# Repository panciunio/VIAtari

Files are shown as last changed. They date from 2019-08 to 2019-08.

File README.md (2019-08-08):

# VIAtari

**Welcome to the VIAtari wiki!**

**Introduction**
Inspiration for this mode I found on Daryl's Computer Hobby Page. Daryl made Composite Video Text/Graphics Display based on ATMEGA8 and drive by VIA6522. This article will show how to build, assembly and connect VIA 6522 IC to Atari and use 2 additional 8-bit parallel ports and serial interface. This is my own project build from scratch but it's nothing modern - this IC was used in C64 to communicate with disk drive. It will be used as additional PIA for manage other equipment.

Notice:
This implementation is designed for Atari 65/130XE with CART/ECI ports available. It's called VIAtariXE

**Why?**
Well, on the market you may find a few sellers which have VIA6522, but...
- this IC is discontinued, don't wait so much time, buy it!
- it's still very useful and may be good alternative for PIA 6520(6521).
- topology and registers covering PIA 6520, so you may use it as equivalent for it. (some pins should be swapped)
- very cheap IC (~2$/piece).

**Best sources**
Original source:
https://systemembedded.eu/viewtopic.php?f=28&t=41

**Discussion (Polish)**

http://www.atari.org.pl/forum/viewtopic.php?id=16098

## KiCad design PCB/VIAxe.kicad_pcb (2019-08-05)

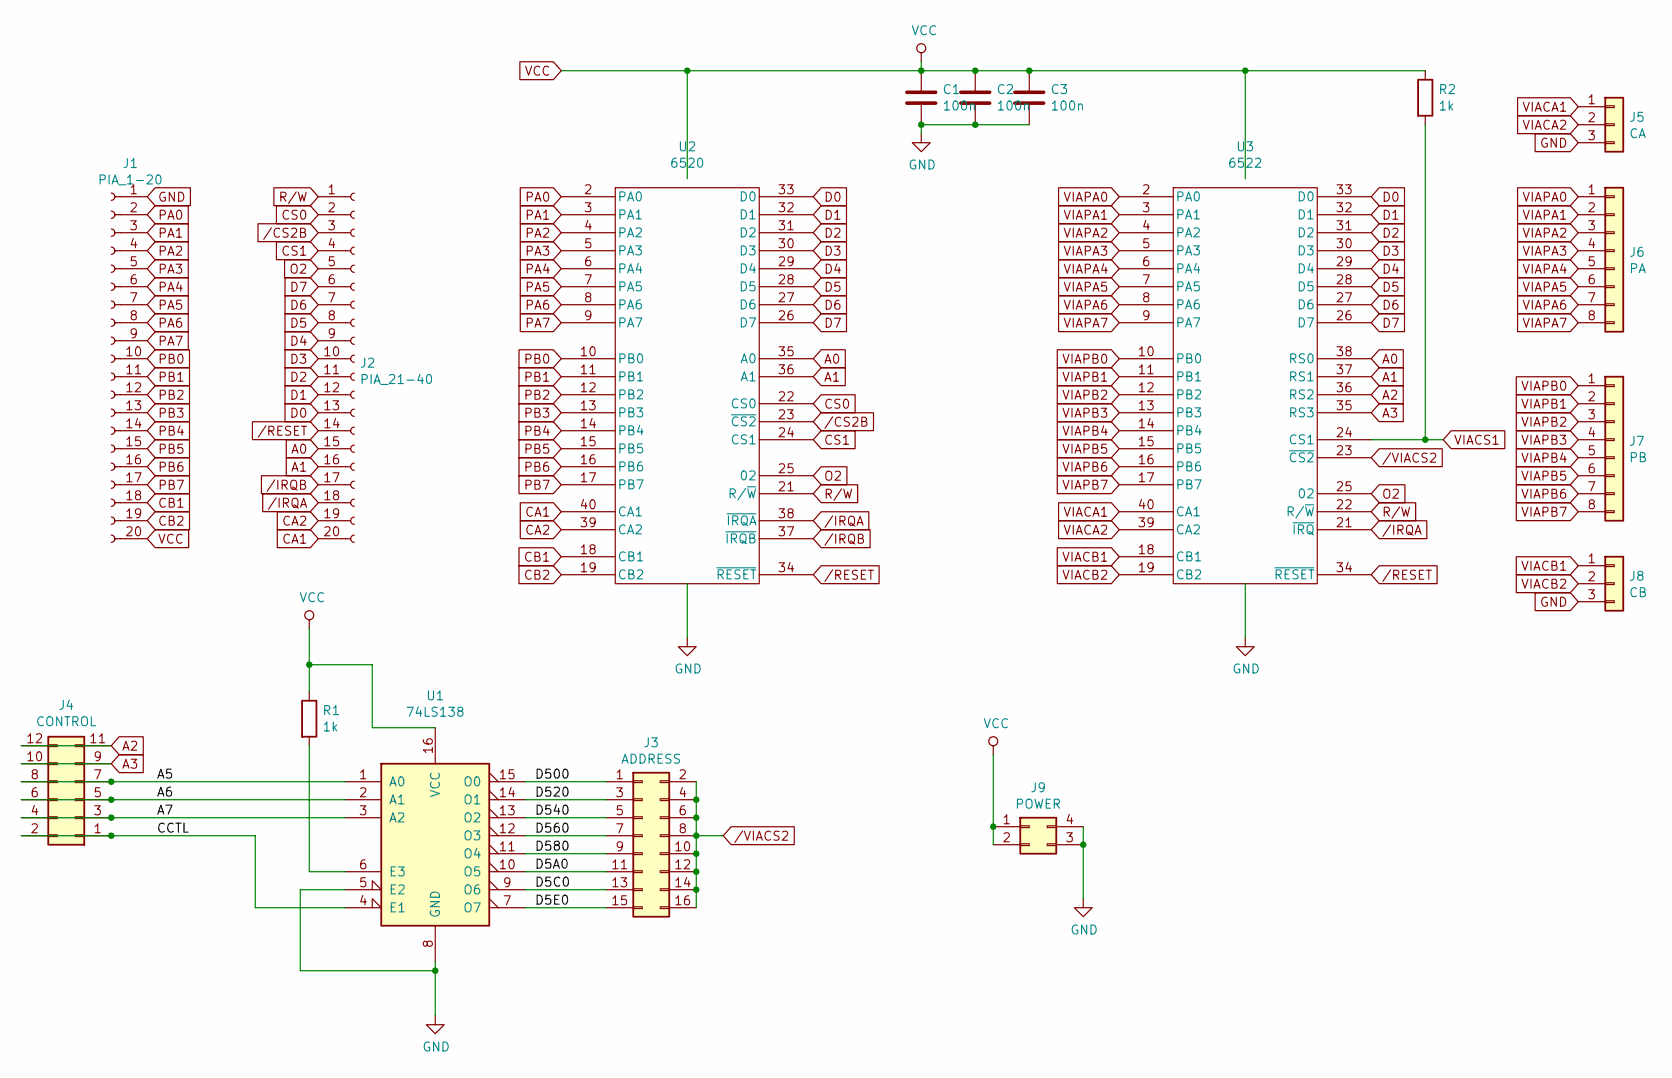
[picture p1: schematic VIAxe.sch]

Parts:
C1, C2, C3: 100n; C_1206_3216Metric
J1: PIA_1-20; PinSocket_1x20_P2.54mm_Vertical
J2: PIA_21-40; PinSocket_1x20_P2.54mm_Vertical
J3: ADDRESS; PinHeader_2x08_P2.54mm_Vertical
J4: CONTROL; PinHeader_2x06_P2.54mm_Vertical
J5: CA; PinHeader_1x03_P2.54mm_Vertical
J6: PA; PinHeader_1x08_P2.54mm_Vertical
J7: PB; PinHeader_1x08_P2.54mm_Vertical
J8: CB; PinHeader_1x03_P2.54mm_Vertical
J9: POWER; PinHeader_2x02_P2.54mm_Vertical
R1, R2: 1k; R_1206_3216Metric
U1: 74LS138; SOP-16_4.4x10.4mm_P1.27mm
U2: 6520; DIP-40_W15.24mm_LongPads
U3: 6522; DIP-40_W15.24mm_LongPads

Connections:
/A5: J4.7, J4.8, U1.1 (A0)
/A6: J4.5, J4.6, U1.2 (A1)
/A7: J4.3, J4.4, U1.3 (A2)
/CCTL: J4.1, J4.2, U1.4 (E1)
/CS2B: J2.3, U2.23 (~CS2)
/D5A0: J3.11, U1.10 (O5)
/D5C0: J3.13, U1.9 (O6)
/D5E0: J3.15, U1.7 (O7)
/D500: J3.1, U1.15 (O0)
/D520: J3.3, U1.14 (O1)
/D540: J3.5, U1.13 (O2)
/D560: J3.7, U1.12 (O3)
/D580: J3.9, U1.11 (O4)
/IRQA: J2.18, U2.38 (~IRQA), U3.21 (~IRQ)
/IRQB: J2.17, U2.37 (~IRQB)
/RESET: J2.14, U2.34 (~RESET), U3.34 (~RESET)
/VIACS2: J3.2, J3.4, J3.6, J3.8, J3.10, J3.12, J3.14, J3.16, U3.23 (~CS2)
A0: J2.15, U2.35 (A0), U3.38 (RS0)
A1: J2.16, U2.36 (A1), U3.37 (RS1)
A2: J4.11, J4.12, U3.36 (RS2)
A3: J4.9, J4.10, U3.35 (RS3)
CA1: J2.20, U2.40 (CA1)
CA2: J2.19, U2.39 (CA2)
CB1: J1.18, U2.18 (CB1)
CB2: J1.19, U2.19 (CB2)
CS0: J2.2, U2.22 (CS0)
CS1: J2.4, U2.24 (CS1)
D0: J2.13, U2.33 (D0), U3.33 (D0)
D1: J2.12, U2.32 (D1), U3.32 (D1)
D2: J2.11, U2.31 (D2), U3.31 (D2)
D3: J2.10, U2.30 (D3), U3.30 (D3)
D4: J2.9, U2.29 (D4), U3.29 (D4)
D5: J2.8, U2.28 (D5), U3.28 (D5)
D6: J2.7, U2.27 (D6), U3.27 (D6)
D7: J2.6, U2.26 (D7), U3.26 (D7)
GND: C1.2, C2.2, C3.2, J1.1, J5.3, J8.3, J9.3, J9.4, U1.5 (E2), U1.8 (GND), U2.1 (GND), U3.1 (GND)
unnamed: R1.2, U1.6 (E3)
O2: J2.5, U2.25 (02), U3.25 (02)
PA0: J1.2, U2.2 (PA0)
PA1: J1.3, U2.3 (PA1)
PA2: J1.4, U2.4 (PA2)
PA3: J1.5, U2.5 (PA3)
PA4: J1.6, U2.6 (PA4)
PA5: J1.7, U2.7 (PA5)
PA6: J1.8, U2.8 (PA6)
PA7: J1.9, U2.9 (PA7)
PB0: J1.10, U2.10 (PB0)
PB1: J1.11, U2.11 (PB1)
PB2: J1.12, U2.12 (PB2)
PB3: J1.13, U2.13 (PB3)
PB4: J1.14, U2.14 (PB4)
PB5: J1.15, U2.15 (PB5)
PB6: J1.16, U2.16 (PB6)
PB7: J1.17, U2.17 (PB7)
R/W: J2.1, U2.21 (R/~W), U3.22 (R/~W)
VCC: C1.1, C2.1, C3.1, J1.20, J9.1, J9.2, R1.1, R2.1, U1.16 (VCC), U2.20 (Vcc), U3.20 (Vcc)
VIACA1: J5.1, U3.40 (CA1)
VIACA2: J5.2, U3.39 (CA2)
VIACB1: J8.1, U3.18 (CB1)
VIACB2: J8.2, U3.19 (CB2)
VIACS1: R2.2, U3.24 (CS1)
VIAPA0: J6.1, U3.2 (PA0)
VIAPA1: J6.2, U3.3 (PA1)
VIAPA2: J6.3, U3.4 (PA2)
VIAPA3: J6.4, U3.5 (PA3)
VIAPA4: J6.5, U3.6 (PA4)
VIAPA5: J6.6, U3.7 (PA5)
VIAPA6: J6.7, U3.8 (PA6)
VIAPA7: J6.8, U3.9 (PA7)
VIAPB0: J7.1, U3.10 (PB0)
VIAPB1: J7.2, U3.11 (PB1)
VIAPB2: J7.3, U3.12 (PB2)
VIAPB3: J7.4, U3.13 (PB3)
VIAPB4: J7.5, U3.14 (PB4)
VIAPB5: J7.6, U3.15 (PB5)
VIAPB6: J7.7, U3.16 (PB6)
VIAPB7: J7.8, U3.17 (PB7)

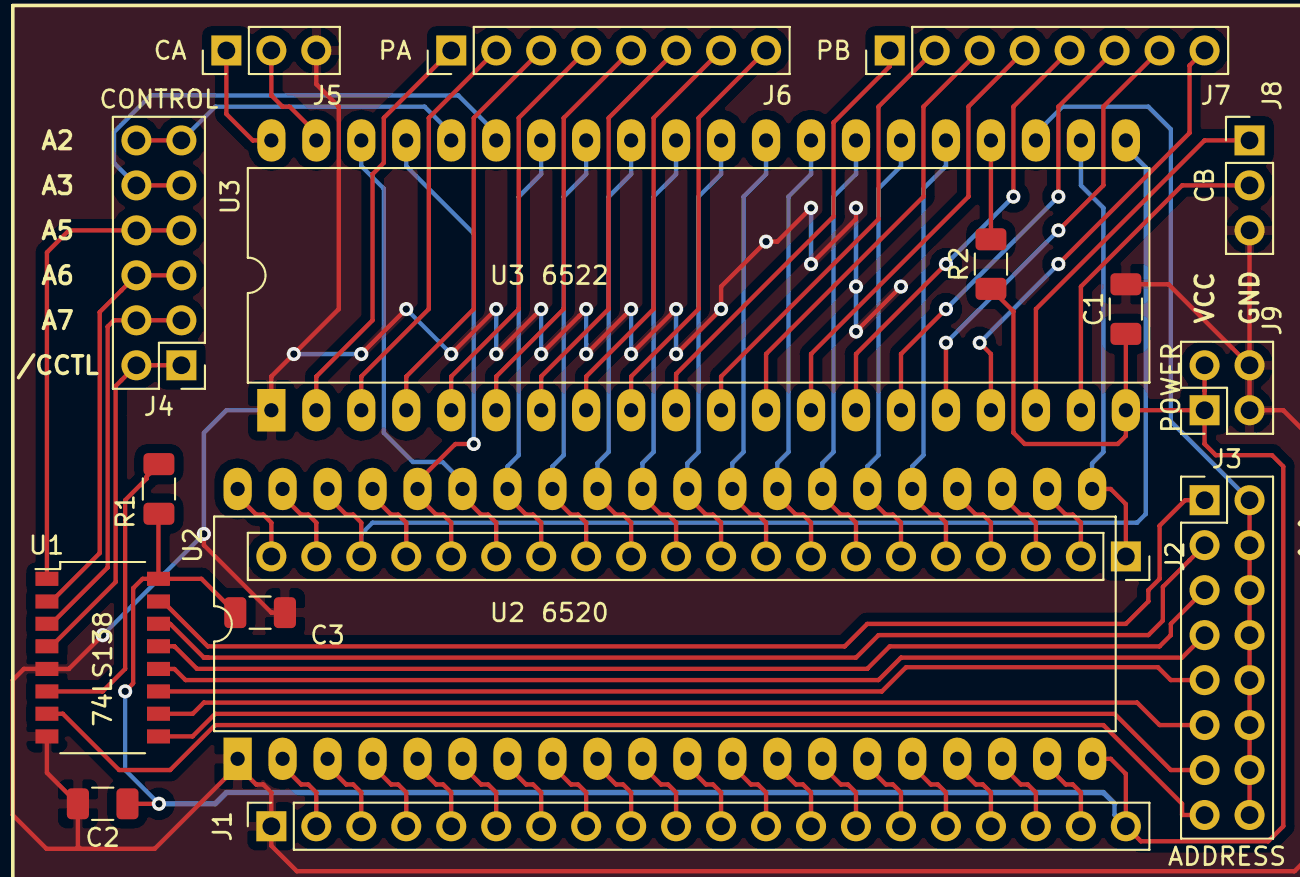
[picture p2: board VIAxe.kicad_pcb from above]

Board: 2 copper layers, 17 parts (0 on the bottom side), 77 nets.

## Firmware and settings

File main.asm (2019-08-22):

;  main.asm    
;  
;  Copyright 2018 pancio <pancio@pancio.net>
;  
;  This program is free software; you can redistribute it and/or modify
;  it under the terms of the GNU General Public License as published by
;  the Free Software Foundation; either version 2 of the License, or
;  (at your option) any later version.
;  
;  This program is distributed in the hope that it will be useful,
;  but WITHOUT ANY WARRANTY; without even the implied warranty of
;  MERCHANTABILITY or FITNESS FOR A PARTICULAR PURPOSE.  See the
;  GNU General Public License for more details.
;  
;  You should have received a copy of the GNU General Public License
;  along with this program; if not, write to the Free Software
;  Foundation, Inc., 51 Franklin Street, Fifth Floor, Boston,
;  MA 02110-1301, USA.

keycode equ $02fc
random  equ $d20a

; known subroutines (S1D15705.asm):
;
;lcd_init:
;   don't need any args
;
;lcd_clear:
;   don't need any args
;
;lcd_pfill:
;   A - pattern to fill display memory
;
;lcd_write_com:
;   A - command to write to LCD
;
;lcd_write_data
;   A - data to send to display memory

; waitkbs:  
;   wait for key
;       A - defined key code
;


;variables on 0 page        
        org $80
        
adr     .ds 2
x       .ds 1
y       .ds 1
a       .ds 1       


        org   $6000
         
;main program         
        
         
start   jsr     via_init            ; set VIA ports
        jsr     lcd_init            ; display initialization
        jsr     lcd_clear
       
        lda     #$ff               ; write pattern to LCD memory
        sta     pattern
        jsr     lcd_pfill
        
        lda     #$21
        ;jsr     waitkbs

 ;test lcd 
                
        ldx     #$00
charl0  lda     font5x8,x                                                   
        eor     #$ff
        sta     lcd_page0,x
        inx
        cpx     #(LCD_MAX_COLLS - 2)      
        bne     charl0
        
        jsr     frm2lcd
         
        lda     #$21
        ;jsr     waitkbs     
 
        
        ldx     #$00
charl1  lda     $e000,x
        sta     lcd_page1,x
        inx
        cpx     #(LCD_MAX_COLLS - 2)      
        bne     charl1
        
        jsr     frm2lcd
        
        lda     #$21
        ;jsr     waitkbs

        
        ldx     #$00                ; get data from Atari chars generator (ROM)
charl2  lda     $e100,x
        sta     lcd_page2,x
        inx
        cpx     #(LCD_MAX_COLLS - 2)     
        bne     charl2
        
        jsr     frm2lcd
        
        lda     #$21
        ;jsr     waitkbs


        
        ldx     #$00
charl3  lda     $e200,x
        sta     lcd_page3,x
        inx
        cpx     #(LCD_MAX_COLLS - 2)    
        bne     charl3    
        
        jsr     frm2lcd
       
        lda     #$21
        ;jsr     waitkbs             


        
        ldx     #$00
charl4  lda     $e300,x
        sta     lcd_page4,x
        inx
        cpx     #(LCD_MAX_COLLS - 2)     
        bne     charl4 

        jsr     frm2lcd

        lda     #$21
        ;jsr     waitkbs     
        

        
        ldx     #$00
charl5  lda     font8x8,x
        eor     #$ff
        sta     lcd_page5,x
        inx
        cpx     #(LCD_MAX_COLlS - 2)    ;don't fill last 2 colls  
        bne     charl5 
        
        jsr     frm2lcd
        
        lda     #$21
        ;jsr     waitkbs 



        
mloop:
        ldx     #$00
ml0     lda     random
        adc     #$aa
        sta     lcd_page7,x
        and     random
        sta     lcd_page6,x
        and     random
        sta     lcd_page5,x
        and     random
        sta     lcd_page4,x
        and     random
        sta     lcd_page3,x
        and     random
        sta     lcd_page2,x
        and     random
        sta     lcd_page1,x
        and     random
        sta     lcd_page0,x
        inx
        cpx     #LCD_MAX_COLLS +1 
        bne     ml0
        
        jsr     frm2lcd
        
        lda     keycode
        cmp     #$21
        beq     next
            
        jmp     mloop
        
next:
        jsr frmclear
        
 
        lda #$00
        tax
        tay
        
ploop   sty x
        stx y
        sta a
        
        sec
        jsr plot

        
        lda a
        ldx y
        ldy x
        
        iny
        cpy #$a2
        bne ploop

        jsr frm2lcd

        ldy #$00
        
        inx
        cpx #$40
        bne ploop

        ldx #$00
        ldy #$00

ploop2  txs
        tya
        pha
        
        clc
        jsr plot

        
        pla
        tay
        tsx
        
        iny
        cpy #$a2
        bne ploop2

        jsr frm2lcd

        ldy #$00
        
        inx
        cpx #$40
        bne ploop2 
        


_plop3  lda #$00
        tax
        tay

ploop3  sty x
        stx y
        sta a
        
        lda random
        rol
        ;sec
        jsr plot

        
        lda a
        ldx y
        ldy x
        
        iny
        cpy #$a2
        bne ploop3

        ;jsr frm2lcd

        ldy #$00
        
        inx
        cpx #$40
        bne ploop3
        
        jsr frm2lcd
        

        ldx #$00
        ldy #$00

ploop4  txs
        tya
        pha

        lda random
        rol        
        ;clc
        jsr plot

        
        pla
        tay
        tsx
        
        iny
        cpy #$a2
        bne ploop4

        ;jsr frm2lcd

        ldy #$00
        
        inx
        cpx #$40
        bne ploop4 
        
        jsr frm2lcd
        
        lda  keycode
        cmp #$0c
        bne _plop3
         
               
        
         
stop:   
        jsr frmclear
        jsr frm2lcd
        brk



;subroutines
waitkbs:
        pha
              
        lda     #$ff
        sta     keycode
        
        pla
        
kbloop  cmp     keycode
        bne     kbloop
        
        lda     #$ff
        sta     keycode
        
        rts

        ICL "VIA6522.asm"
        ICL "S1D15705.asm"
 

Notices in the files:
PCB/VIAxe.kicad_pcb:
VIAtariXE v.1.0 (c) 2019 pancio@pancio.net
